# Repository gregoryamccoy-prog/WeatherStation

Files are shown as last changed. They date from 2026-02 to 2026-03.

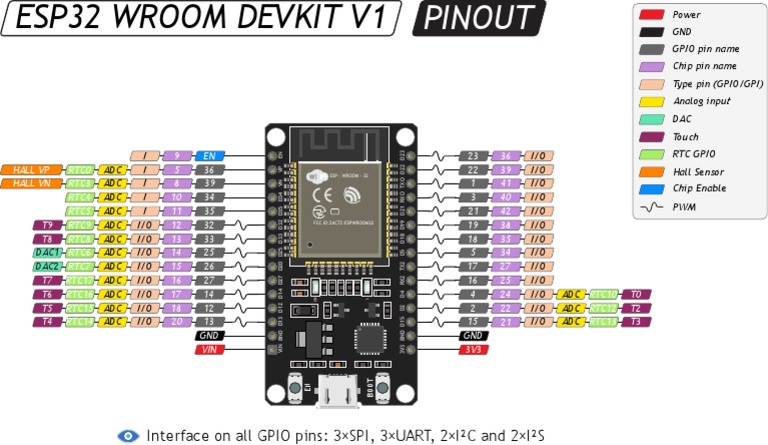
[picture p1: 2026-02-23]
zho_Esp32-Wroom-32-Arduino-Pinout.jpg

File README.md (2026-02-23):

# ESP32 Weather Station

A low-power indoor/outdoor weather station built on the ESP32 WROOM. It reads indoor conditions from a DHT11 sensor, fetches outdoor weather and a 3-day forecast from the [Open-Meteo](https://open-meteo.com/) API (no API key required), and renders the full layout onto a Waveshare 4.2" e-paper display. The device wakes every 10 minutes, completes its update cycle in under 15 seconds, then returns to deep sleep.

---

## Table of Contents

1. [Hardware Bill of Materials](#hardware-bill-of-materials)
2. [Wiring Diagram](#wiring-diagram)
3. [Pin Reference](#pin-reference)
4. [Software Setup](#software-setup)
5. [Configuration](#configuration)
6. [Build & Flash](#build--flash)
7. [Operation](#operation)
8. [Display Layout](#display-layout)
9. [Project Structure](#project-structure)
10. [Performance Targets](#performance-targets)
11. [Troubleshooting](#troubleshooting)

---

## Hardware Bill of Materials

| # | Component | Notes |
|---|---|---|
| 1 | **ESP32 WROOM Dev Module** | Any standard 38-pin board |
| 2 | **Waveshare 4.2" e-Paper Display** | Rev 2.1, GDEW042T2, 400 × 300 px B/W |
| 3 | **DHT11 Temperature & Humidity Sensor** | 3-pin breakout or 4-pin module with pull-up |
| 4 | **10 kΩ resistor** | Pull-up on DHT11 DATA line (omit if using breakout with built-in resistor) |
| 5 | **Breadboard / PCB + jumper wires** | — |
| 6 | **5 V USB power supply** | Powers the ESP32 via its onboard regulator |

---

## Wiring Diagram

```
                        ┌──────────────────────────────────────────┐
                        │           ESP32 Dev Module               │
                        │                                          │
          ┌─── 3.3V ────┤ 3V3                               GPIO23 ├──── MOSI ────┐
          │  ┌── GND ───┤ GND                               GPIO18 ├──── SCK  ────┤
          │  │          │                                   GPIO 5 ├──── CS   ────┤
          │  │          │                                   GPIO16 ├──── DC   ────┤  Waveshare
          │  │          │                                   GPIO17 ├──── RST  ────┤  4.2" e-Paper
          │  │          │                                   GPIO25 ├──── BUSY ────┘  (SPI)
          │  │          │                                          │
          │  │          │                                   GPIO26 ├──── DATA ────┐
          │  │          │                                          │              │  DHT11
          └──┼──────────┤ 3V3  ◄────────────────────────── VCC   │◄─────────────┤
             └──────────┤ GND  ◄────────────────────────── GND   │              │
                        └──────────────────────────────────────────┘             │
                                                                    10kΩ to 3.3V ┘
                                                                    (pull-up, if needed)
```

### Schematic (Mermaid)

```mermaid
graph TD
    subgraph ESP32["ESP32 WROOM Dev Module"]
        P23["GPIO 23 — MOSI"]
        P18["GPIO 18 — SCK"]
        P5["GPIO 5  — CS"]
        P16["GPIO 16 — DC"]
        P17["GPIO 17 — RST"]
        P25["GPIO 25 — BUSY"]
        P26["GPIO 26 — DHT DATA"]
        V33["3.3 V"]
        GND["GND"]
    end

    subgraph EPD["Waveshare 4.2&quot; e-Paper (SPI)"]
        E_DIN["DIN (MOSI)"]
        E_CLK["CLK (SCK)"]
        E_CS["CS"]
        E_DC["DC"]
        E_RST["RST"]
        E_BUSY["BUSY"]
        E_VCC["VCC"]
        E_GND["GND"]
    end

    subgraph DHT["DHT11 Sensor"]
        D_DATA["DATA"]
        D_VCC["VCC"]
        D_GND["GND"]
    end

    P23  --> E_DIN
    P18  --> E_CLK
    P5   --> E_CS
    P16  --> E_DC
    P17  --> E_RST
    E_BUSY --> P25
    V33  --> E_VCC
    GND  --> E_GND

    P26  --> D_DATA
    V33  --> D_VCC
    GND  --> D_GND
```

---

## Pin Reference

### e-Paper Display — SPI

| Display Pin | ESP32 GPIO | Notes |
|---|---|---|
| DIN (MOSI)  | **23** | SPI data |
| CLK (SCK) | **18** | SPI clock |
| CS | **5** | Chip select (active LOW) |
| DC | **16** | Data / Command select |
| RST | **17** | Hardware reset (active LOW) |
| BUSY | **25** | High while display is refreshing |
| VCC | 3.3 V | — |
| GND | GND | — |

### DHT11 Sensor

| Sensor Pin | ESP32 GPIO | Notes |
|---|---|---|
| DATA | **26** | Add 10 kΩ pull-up to 3.3 V if using bare IC |
| VCC | 3.3 V | — |
| GND | GND | — |

> **Note:** All signal lines run at 3.3 V logic. The ESP32's onboard 3.3 V LDO supplies both peripherals; total current draw at peak (Wi-Fi TX + SPI) stays well within its 600 mA rating.

---

## Software Setup

### Prerequisites

- [PlatformIO](https://platformio.org/) (VS Code extension or CLI)
- USB driver for your ESP32 board (CP210x or CH340, depending on board variant)

### Library Dependencies

Managed automatically by PlatformIO via `platformio.ini`:

| Library | Version | Purpose |
|---|---|---|
| `zinggjm/GxEPD2` | ^1.6.0 | e-Paper driver (GxEPD2_420 / GDEW042T2) |
| `bblanchon/ArduinoJson` | ^7.0.0 | JSON parsing (v7 `JsonDocument`) |
| `adafruit/DHT sensor library` | ^1.4.6 | DHT11 driver |
| `adafruit/Adafruit Unified Sensor` | ^1.1.14 | Sensor abstraction |
| `HTTPClient` | (bundled) | HTTP requests |
| `WiFiClientSecure` | (bundled) | HTTPS (TLS with `setInsecure()`) |
| `Preferences` | (bundled) | NVS storage |

---

## Configuration

### Wi-Fi Credentials — `secrets.h`

Create `secrets.h` in the **project root** (it is excluded from version control via `.gitignore`):

```cpp
// secrets.h
#pragma once

#define WIFI_SSID     "your-network-name"
#define WIFI_PASSWORD "your-network-password"
```

### Location & Time Zone — `src/config.h`

Edit these constants if you are not in Crestwood, KY:

```cpp
static constexpr double LOCATION_LAT  =  38.3242;
static constexpr double LOCATION_LON  = -85.4725;
static constexpr char   LOCATION_TZ[] = "America/New_York";
static constexpr char   LOCATION_NAME[] = "Crestwood, KY";

static constexpr long GMT_OFFSET_SEC  = -18000;   // UTC-5 (EST)
static constexpr int  DAYLIGHT_OFFSET = 3600;      // +1 h during EDT
```

> **Remember** to also update the latitude/longitude in `OPENMETEO_URL` inside `config.h` to match.

### Sleep Interval — `src/config.h`

```cpp
static constexpr uint64_t SLEEP_DURATION_US = 10ULL * 60ULL * 1000000ULL;  // 10 minutes
```

---

## Build & Flash

```bash
# Build only
pio run

# Build and upload
pio run --target upload

# Monitor serial output
pio device monitor --baud 115200
```

Or use the **PlatformIO: Build / Upload** buttons in VS Code.

> **Stack size:** The Arduino loop task stack is set to **16 KB** (`-DARDUINO_LOOP_STACK_SIZE=16384` in `platformio.ini`) to accommodate GxEPD2 page-buffered rendering alongside the `WeatherSnapshot` struct and font rendering.

---

## Operation

### Wake Sequence (every 10 minutes)

```
Power-on / RTC wakeup
        │
        ▼
  Init e-paper hardware (before Wi-Fi to avoid heap fragmentation)
        │
        ▼
  Connect Wi-Fi  ──(fail)──► render cached data → deep sleep
        │
        ▼
  NTP sync (once per calendar day)
        │
        ▼
  Read DHT11 (up to 3 retries, 2 s apart)
        │
        ▼
  HTTPS GET Open-Meteo API → getString() → deserializeJson()
        │
        ▼
  Write NVS trend record (once per calendar day, if sensor + API both OK)
        │
        ▼
  Render framebuffer → full e-paper refresh
        │
        ▼
  Deep sleep 10 min
```

### Offline Behaviour

If the Wi-Fi connection or API call fails, the device will:
- Display the last successfully fetched weather data (cached in RTC memory)
- Show "! Offline – cached data" warning and "Offline" in the top bar
- Still display live indoor sensor readings
- Continue the normal sleep / wake cycle

### RTC-Retained State

Across deep-sleep cycles, the following are preserved in RTC memory:
- Last successful `CurrentConditions` and `ForecastDay[3]`
- Timestamp of last successful API call
- Day-of-year of last NTP sync and last NVS trend write
- Wake counter

### NVS Trend Storage

Up to **365 daily records** are stored in NVS flash using a circular buffer. Each record (18 bytes) contains:
- Day index (days since epoch)
- Indoor temperature & humidity
- Outdoor temperature
- Barometric pressure

The **30 most recent** records are rendered as a dual-line trend graph at the bottom of the display (indoor = solid, outdoor = dotted).

---

## Display Layout

The display is a 400 × 300 px monochrome e-paper panel rendered with GxEPD2 page-buffered drawing and Adafruit GFX (FreeSans) fonts.

```
┌────────────────────────────────────────────────────────────────┐  y=0
│  22:05       Sun Feb 22                            Online     │  Top bar (22 px)
├──────────┬──────────────────────────┬─────────────────────────┤  y=22
│ INDOOR   │                          │  WIND                   │
│ 22.5°C   │      -4.7°              │  22 km/h                │
│ 32% RH   │   Partly Cloudy         │─────────────────────────│  Main panels
│──────────│      ⛅ (48×48 icon)     │  PRESSURE               │  (133 px)
│          │                          │  1018 hPa               │
│          │                          │─────────────────────────│
│          │                          │  HUMIDITY               │
│          │                          │  74%                    │
├──────────┴──────────────────────────┴─────────────────────────┤  y=155
│    TODAY         TMRW          +2 DAY                         │
│  4 / -1°C     6 / 0°C        8 / 2°C                         │  Forecast (62 px)
│  Rain 20%     Rain 60%       Rain 10%                         │
├───────────────────────────────────────────────────────────────┤  y=217
│  Rise 07:12     Set 17:48     Wax Cresc                       │  Astronomy (20 px)
├───────────────────────────────────────────────────────────────┤  y=237
│  30d  IN ───  OUT · · ·   (auto-scaled line graph)            │  Trend graph (63 px)
└───────────────────────────────────────────────────────────────┘  y=300
```

**Panel widths:** Left 100 px · Centre 200 px · Right 100 px

### Fonts

| Zone | Font | Size |
|---|---|---|
| Top bar | FreeSansBold | 9 pt |
| Indoor label | FreeSans | 9 pt |
| Indoor temp | FreeSansBold | 12 pt |
| Outdoor temp | FreeSansBold | 18 pt |
| Weather desc | FreeSans | 9 pt |
| Right panel labels | FreeSans | 9 pt |
| Right panel values | FreeSansBold | 9 pt |
| Forecast day labels | FreeSansBold | 9 pt |
| Forecast data | FreeSans | 9 pt |
| Astronomy bar | FreeSans | 9 pt |
| Trend graph label | Built-in 6×8 | 1× |

### Weather Icons

48 × 48 px icons drawn with Adafruit GFX primitives (circles, lines, rectangles) — no bitmaps. Mapped from WMO weather codes:

| WMO Code | Icon | Description |
|---|---|---|
| 0 | Sun | Clear sky |
| 1–3 | Sun + cloud | Partly cloudy |
| 45–48 | Dashed lines | Fog |
| 51–67 | Cloud + drops | Rain |
| 71–77 | Cloud + flakes | Snow |
| 80–82 | Outline cloud + drops | Showers |
| 95–99 | Cloud + bolt | Thunderstorm |
| Other | Circle + ? | Unknown |

### Moon Phase

Calculated locally from a synodic-period algorithm (reference new moon: 2000-01-06 18:14 UTC). Labels: New, Wax Cresc, 1stQtr, Wax Gibb, Full, Wan Gibb, LastQtr, Wan Cresc.

---

## Project Structure

```
WeatherStation/
├── platformio.ini              # Build config, libs, stack size (16 KB)
├── secrets.h                   # Wi-Fi credentials (git-ignored)
├── README.md                   # This file
├── ESP32 Weather Station – Product Requirements.md
└── src/
    ├── main.cpp                # Wake/sleep orchestration, RTC-retained state
    ├── config.h                # Pins, API URL, layout geometry, NVS keys
    ├── data_model.h            # Shared structs (CurrentConditions, ForecastDay,
    │                           #   DailyTrend, SensorReading, WeatherSnapshot)
    ├── wifi_manager/           # Wi-Fi connect/disconnect with configurable timeout
    │   ├── wifi_manager.h
    │   └── wifi_manager.cpp
    ├── ntp_service/            # SNTP sync (once per calendar day via RTC check)
    │   ├── ntp_service.h
    │   └── ntp_service.cpp
    ├── openmeteo_client/       # HTTPS GET → getString() → ArduinoJson v7 parsing
    │   ├── openmeteo_client.h  #   Moon phase calculated locally (not from API)
    │   └── openmeteo_client.cpp
    ├── sensor_service/         # DHT11 read with retry logic (up to 3 attempts)
    │   ├── sensor_service.h
    │   └── sensor_service.cpp
    ├── trend_storage/          # NVS circular buffer (365 records, daily writes)
    │   ├── trend_storage.h
    │   └── trend_storage.cpp
    ├── display_renderer/       # GxEPD2 page-buffered layout, GFX fonts & icons
    │   ├── display_renderer.h
    │   ├── display_renderer.cpp
    │   └── icon_renderer.h     # 48×48 vector icons drawn via GFX primitives
    └── power_manager/          # Deep sleep entry
        ├── power_manager.h
        └── power_manager.cpp
```

---

## Performance Targets

| Metric | Target |
|---|---|
| Wi-Fi connect | < 4 s |
| API call + parse | < 3 s |
| Render + refresh | < 4 s |
| **Total active time** | **≤ 15 s** |
| Sleep current | ~10 µA (ESP32 deep sleep) |
| Wake interval | 10 minutes |
| RAM usage | ~19% (62 KB / 328 KB) |
| Flash usage | ~49% (953 KB / 1966 KB) |

---

## Weather API

**Provider:** [Open-Meteo](https://open-meteo.com/) — no API key required.

**Endpoint (configured in `src/config.h`):**
```
https://api.open-meteo.com/v1/forecast
  ?latitude=38.3242&longitude=-85.4725
  &current=temperature_2m,relative_humidity_2m,pressure_msl,wind_speed_10m,weather_code
  &daily=weather_code,temperature_2m_max,temperature_2m_min,
         precipitation_probability_max,sunrise,sunset
  &timezone=auto
  &forecast_days=3
```

A single HTTPS request returns current conditions and a 3-day forecast (~3 KB payload), minimising Wi-Fi on-time per cycle. Moon phase is computed locally rather than requested from the API.

---

## Troubleshooting

| Symptom | Cause | Fix |
|---|---|-----|
| `JSON parse error: InvalidInput` | Chunked transfer encoding on HTTPS stream | Fixed: uses `getString()` instead of stream parsing |
| `stack overflow in task loopTask` | Default 8 KB stack too small for GxEPD2 + fonts | Fixed: stack set to 16 KB in `platformio.ini` |
| Display renders upside-down | Wrong `setRotation()` value | Set `display.setRotation(0)` for connector-at-top mounting |
| Text overlapping / 2× scale | Icon renderer leaking `setTextSize(2)` | Fixed: `drawUnknown()` now resets to `setTextSize(1)` |
| DHT reads `NaN` | Sensor needs 2 s warm-up after power-on | Built-in: 2 s delay on first read, 3 retries |
| Wi-Fi fails | Weak signal or wrong credentials | Check `secrets.h`; timeout is 20 s (configurable) |

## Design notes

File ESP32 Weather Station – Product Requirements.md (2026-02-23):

# ESP32 Weather Station – Product Requirements Document (PRD)

## 1. Product Overview

### 1.1 Objective

Design a low-power ESP32-based indoor/outdoor weather station that:

- Measures indoor temperature and humidity using a DHT11 sensor
- Retrieves outdoor weather and a 3-day forecast from the Open-Meteo API (no API key)
- Displays sunrise, sunset, and lunar phase
- Stores long-term trend data in NVS flash (365 days)
- Operates on a 10-minute deep-sleep cycle
- Renders all data onto a Waveshare 4.2" 400 × 300 e-paper display

### 1.2 Hardware

| Component | Detail |
|---|---|
| MCU | ESP32 WROOM (esp32dev) |
| Display | Waveshare 4.2" 400 × 300 B/W e-paper, Rev 2.1 (GDEW042T2) |
| Sensor | DHT11 (temperature + humidity) |
| Build platform | PlatformIO, Arduino framework |

### 1.3 Location

Crestwood, Kentucky (38.3242, -85.4725). Timezone: America/New_York. Units: Metric.

---

## 2. Weather Data Provider

### 2.1 Selected Service: Open-Meteo

- **No API key required** — eliminates TLS token exchange overhead and rate-limit concerns for a single device.
- Base URL: `https://api.open-meteo.com/v1/forecast`

### 2.2 API Request

```
https://api.open-meteo.com/v1/forecast
  ?latitude=38.3242&longitude=-85.4725
  &current=temperature_2m,relative_humidity_2m,pressure_msl,wind_speed_10m,weather_code
  &daily=weather_code,temperature_2m_max,temperature_2m_min,
         precipitation_probability_max,sunrise,sunset
  &timezone=auto
  &forecast_days=3
```

A single HTTPS request returns:
- Current conditions (temperature, humidity, pressure, wind, WMO weather code)
- 3-day daily forecast (min/max temp, rain probability, sunrise, sunset)

**Moon phase** is not requested from the API; it is calculated locally using a synodic-period algorithm.

### 2.3 Response Handling

- HTTPS via `WiFiClientSecure` with `setInsecure()` (no CA bundle on device).
- Full response body read via `http.getString()` to correctly handle chunked transfer encoding.
- Parsed with ArduinoJson v7 (`JsonDocument`, heap-allocated, ~3–5 KB payload).

---

## 3. Weather Code → Icon Mapping

Open-Meteo uses WMO numeric `weather_code` values. The firmware maps these to vector icons drawn with Adafruit GFX primitives (48 × 48 px, no bitmaps):

| WMO Code | Icon | Description |
|---|---|---|
| 0 | Sun | Clear sky |
| 1–3 | Sun + cloud | Partly cloudy |
| 45–48 | Dashed lines | Fog |
| 51–67 | Cloud + drops | Rain |
| 71–77 | Cloud + flakes | Snow |
| 80–82 | Outline cloud + drops | Showers |
| 95–99 | Cloud + bolt | Thunderstorm |
| Other | Circle + ? | Unknown |

---

## 4. Data Model

### 4.1 Current Conditions

```cpp
struct CurrentConditions {
    float   outdoorTemp;     // °C
    float   pressure;        // hPa
    float   windSpeed;       // km/h
    int     humidity;        // %
    uint8_t weatherCode;     // WMO code
    bool    valid;
};
```

### 4.2 Forecast

```cpp
struct ForecastDay {
    float   minTemp;         // °C
    float   maxTemp;         // °C
    int     rainChance;      // %
    uint8_t weatherCode;
    char    sunrise[6];      // "HH:MM\0"
    char    sunset[6];
    char    moonPhase[16];   // e.g. "Wax Cresc"
    bool    valid;
};
```

### 4.3 Trend Record (NVS)

```cpp
struct DailyTrend {
    uint16_t dayIndex;       // days since epoch
    float    indoorTemp;
    float    indoorHumidity;
    float    outdoorTemp;
    float    pressure;
};
```

- Retention: 365 records in a circular NVS buffer
- Written once per calendar day (only when both sensor and API data are valid)

### 4.4 Indoor Sensor Reading

```cpp
struct SensorReading {
    float temperature;    // °C
    float humidity;       // %
    bool  valid;
};
```

### 4.5 Aggregate Snapshot

```cpp
struct WeatherSnapshot {
    CurrentConditions current;
    ForecastDay       forecast[3];
    SensorReading     indoor;
    DailyTrend        graph[30];   // last ≤30 records for trend graph
    uint8_t           graphCount;
    bool              apiOk;
    time_t            lastUpdate;
};
```

---

## 5. Power and Runtime Model

- **Wake interval:** 10 minutes (configurable via `SLEEP_DURATION_US`)
- **Sleep current:** ~10 µA (ESP32 deep sleep)
- **Target active time:** ≤ 15 seconds

### Active Sequence

1. Init e-paper hardware (before Wi-Fi to avoid heap fragmentation)
2. Connect Wi-Fi (20 s timeout)
3. NTP sync (once per calendar day, tracked via RTC-retained day-of-year)
4. Read DHT11 (up to 3 retries, 2 s between attempts)
5. HTTPS GET Open-Meteo API → `getString()` → `deserializeJson()`
6. Write NVS trend record (once per calendar day)
7. Render framebuffer → full e-paper refresh
8. Deep sleep

### RTC-Retained State

Preserved across deep-sleep cycles:
- Last successful `CurrentConditions` and `ForecastDay[3]`
- Timestamp of last API success
- Day-of-year of last NTP sync and NVS write
- Wake counter

---

## 6. Display Layout

**Resolution:** 400 × 300 px, 1-bit monochrome  
**Driver:** GxEPD2_BW with GxEPD2_420 (page-buffered rendering)  
**Rotation:** 0° (connector at top)

### Layout Zones

| Zone | Y start | Height | Content |
|---|---|---|---|
| Top bar | 0 | 22 px | Time (left), date (centre), Online/Offline (right) |
| Main panels | 22 | 133 px | Left (100 px): indoor. Centre (200 px): outdoor temp + icon. Right (100 px): wind, pressure, humidity |
| Forecast row | 155 | 62 px | 3 columns (133 px each): TODAY, TMRW, +2 DAY with max/min and rain % |
| Astronomy bar | 217 | 20 px | Sunrise, sunset, moon phase label |
| Trend graph | 237 | 63 px | 30-day indoor (solid) + outdoor (dotted) line graph, auto-scaled |

### Fonts

- **FreeSansBold 18pt:** Outdoor temperature (centre panel)
- **FreeSansBold 12pt:** Indoor temperature
- **FreeSansBold 9pt:** Top bar, forecast day labels, panel values
- **FreeSans 9pt:** Labels, descriptions, forecast data, astronomy bar
- **Built-in 6×8:** Trend graph legend

### Moon Phase

Computed locally via synodic-period algorithm (reference new moon: 2000-01-06 18:14 UTC, period: 29.53059 days). Labels: New, Wax Cresc, 1stQtr, Wax Gibb, Full, Wan Gibb, LastQtr, Wan Cresc.

---

## 7. Memory Budget

### 7.1 JSON Document

- Open-Meteo payload (filtered fields): ~3–5 KB
- ArduinoJson v7 `JsonDocument` (heap-allocated, auto-sized)

### 7.2 Framebuffer

- 400 × 300 monochrome: ~15 KB
- GxEPD2 uses page-buffered rendering (not full framebuffer)

### 7.3 Stack

- Arduino loop task stack: **16 KB** (`-DARDUINO_LOOP_STACK_SIZE=16384`)
- Required by GxEPD2 page-write + Adafruit GFX font rendering + `WeatherSnapshot` on stack

### 7.4 Overall

- RAM usage: ~19% (62 KB / 328 KB)
- Flash usage: ~49% (953 KB / 1966 KB)

---

## 8. Flash Storage Strategy

- **Daily write only** — one NVS record per calendar day
- NVS circular buffer: 365 records × 18 bytes ≈ 6.4 KB
- Partition scheme: `min_spiffs.csv` (maximises NVS headroom)
- Flash lifetime: multi-decade at one write/day

---

## 9. Connectivity Behaviour

If API call or Wi-Fi fails:
- Use cached weather data from RTC memory
- Show "! Offline – cached data" overlay + "Offline" in top bar
- Still display live indoor sensor readings
- Continue normal sleep cycle

---

## 10. Firmware Modules

| Module | Directory | Responsibility |
|---|---|---|
| `wifi_manager` | `src/wifi_manager/` | Connect/disconnect with configurable timeout |
| `ntp_service` | `src/ntp_service/` | SNTP sync, once per calendar day |
| `openmeteo_client` | `src/openmeteo_client/` | HTTPS fetch, JSON parse, moon phase calc |
| `sensor_service` | `src/sensor_service/` | DHT11 read with 3-retry logic |
| `trend_storage` | `src/trend_storage/` | NVS circular buffer (365 records) |
| `display_renderer` | `src/display_renderer/` | GxEPD2 layout, fonts, vector icons |
| `power_manager` | `src/power_manager/` | Deep sleep entry |

---

## 11. Performance Targets

| Metric | Target |
|---|---|
| Wi-Fi connect | < 4 s |
| API call + parse | < 3 s |
| Render + refresh | < 4 s |
| **Total active time** | **≤ 15 s** |
| Sleep current | ~10 µA |
| Wake interval | 10 min |

---

## 12. Build Environment

- **PlatformIO** with Arduino framework
- Board: `esp32dev`
- Partition: `min_spiffs.csv`
- Stack: 16 KB loop task
- Libraries: GxEPD2 ^1.6.0, ArduinoJson ^7.0.0, DHT sensor library ^1.4.6, Adafruit Unified Sensor ^1.1.14

---

## 13. Acceptance Criteria

The system shall:

1. Operate with no API key (Open-Meteo)
2. Wake every 10 minutes from deep sleep
3. Display indoor temperature and humidity from DHT11
4. Display outdoor conditions (temp, wind, pressure, humidity, weather icon)
5. Display 3-day forecast (min/max, rain probability)
6. Display sunrise, sunset, and computed moon phase
7. Maintain 365-day trend history in NVS
8. Render 30-day dual-line trend graph (indoor + outdoor)
9. Enter deep sleep automatically after each refresh
10. Recover gracefully from Wi-Fi and API failures using cached data
11. Complete full wake cycle in ≤ 15 seconds
12. Fit within ESP32 RAM (~19%) and flash (~49%) budgets

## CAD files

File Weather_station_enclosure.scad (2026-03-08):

$fn = 96;

// Debug switches
SHOW_2D_ONLY  = true;   // set false once you see silhouette
SHOW_OUTER_3D = false;  // set true to see an extruded slab

tilt_deg   = 10;
fillet_r   = 30;

base_depth = 95;
base_h     = 26;

blade_h    = 135;
blade_back = 10;

module outer_2d() {
  hull() {
    // Base rectangle (electronics volume)
    square([base_depth, base_h], center=false);

    // Blade rectangle (screen “sheet”), tilted
    translate([base_depth - blade_back - 2, base_h])
      rotate(-tilt_deg)
        square([blade_back, blade_h], center=false);

    // Circle to encourage a smooth bend
    translate([base_depth - fillet_r - 6, base_h - fillet_r])
      circle(r=fillet_r);
  }
}

if (SHOW_2D_ONLY) {
  outer_2d();
} else if (SHOW_OUTER_3D) {
  linear_extrude(height=20) outer_2d();
}

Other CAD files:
Enclosure.FCStd

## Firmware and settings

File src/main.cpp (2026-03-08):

// main.cpp — Wake / sleep orchestration for ESP32 Weather Station
//
// Wake sequence:
//   Power on → WiFi → NTP (once/day) → DHT11 → Open-Meteo API →
//   Parse → Render → EPD refresh → Deep sleep 10 min

#include <Arduino.h>
#include <time.h>

#include "config.h"
#include "data_model.h"
#include "secrets.h"

#include "wifi_manager/wifi_manager.h"
#include "ntp_service/ntp_service.h"
#include "openmeteo_client/openmeteo_client.h"
#include "sensor_service/sensor_service.h"
#include "display_renderer/display_renderer.h"
#include "power_manager/power_manager.h"

// ---------------------------------------------------------------------------
// RTC-retained state (survives deep sleep)
// ---------------------------------------------------------------------------
RTC_DATA_ATTR static bool            rtc_initialized         = false;
RTC_DATA_ATTR static CurrentConditions rtc_lastCurrent       = {};
RTC_DATA_ATTR static ForecastDay     rtc_lastForecast[3]     = {};
RTC_DATA_ATTR static time_t          rtc_lastApiSuccess      = 0;
RTC_DATA_ATTR static int             rtc_lastNtpDay          = -1;    // day-of-year of last NTP sync
RTC_DATA_ATTR static uint32_t        rtc_wakeCount           = 0;

// ---------------------------------------------------------------------------
// Helpers
// ---------------------------------------------------------------------------
static int dayOfYear(const struct tm* t) {
    return t->tm_yday;
}

// ---------------------------------------------------------------------------
// setup() — runs once per wake from deep sleep
// ---------------------------------------------------------------------------
void setup() {
    Serial.begin(115200);
    delay(200);   // allow USB-serial bridge to enumerate before first print
    Serial.printf("\n[main] Wake #%u\n", rtc_wakeCount++);

    // -----------------------------------------------------------------------
    // 0. Initialise display hardware FIRST — grabs GxEPD2 heap/DMA allocations
    //    before WiFi stack fragments the heap.
    // -----------------------------------------------------------------------
    DisplayRenderer::init();

    // -----------------------------------------------------------------------
    // 1. Connect to Wi-Fi
    // -----------------------------------------------------------------------
    bool wifiOk = WifiManager::connect(WIFI_SSID, WIFI_PASSWORD, WIFI_CONNECT_TIMEOUT);
    if (!wifiOk) {
        Serial.println("[main] Wi-Fi failed – rendering cached data");
        // Still render whatever is cached so the display doesn't go blank
        WeatherSnapshot snap = {};
        snap.apiOk           = false;
        snap.indoor          = SensorService::read();
        snap.current         = rtc_lastCurrent;
        snap.lastUpdate      = rtc_lastApiSuccess;
        for (int i = 0; i < 3; i++) snap.forecast[i] = rtc_lastForecast[i];
        DisplayRenderer::render(snap);
        PowerManager::deepSleep(SLEEP_DURATION_US);
        return;
    }

    // -----------------------------------------------------------------------
    // 2. NTP sync (once per calendar day)
    // -----------------------------------------------------------------------
    struct tm timeinfo = {};
    bool timeValid     = NtpService::getTime(timeinfo);

    if (!timeValid || dayOfYear(&timeinfo) != rtc_lastNtpDay) {
        Serial.println("[main] Syncing NTP...");
        NtpService::sync();
        if (NtpService::getTime(timeinfo)) {
            rtc_lastNtpDay = dayOfYear(&timeinfo);
            Serial.printf("[main] NTP synced – day %d\n", rtc_lastNtpDay);
        }
    }

    // -----------------------------------------------------------------------
    // 3. Read DHT11
    // -----------------------------------------------------------------------
    SensorReading indoor = SensorService::read();
    Serial.printf("[main] Indoor %.1f°C  %.0f%%RH  valid=%d\n",
                  indoor.temperature, indoor.humidity, indoor.valid);

    // -----------------------------------------------------------------------
    // 4. Fetch Open-Meteo
    // -----------------------------------------------------------------------
    CurrentConditions current   = {};
    ForecastDay       forecast[3] = {};
    bool apiOk = OpenMeteoClient::fetch(current, forecast);

    if (apiOk) {
        rtc_lastCurrent   = current;
        for (int i = 0; i < 3; i++) rtc_lastForecast[i] = forecast[i];
        rtc_lastApiSuccess = time(nullptr);
        Serial.printf("[main] API OK – %.1f°C wmo=%d\n",
                      current.outdoorTemp, current.weatherCode);
    } else {
        Serial.println("[main] API failed – using cached outdoor data");
        current = rtc_lastCurrent;
        for (int i = 0; i < 3; i++) forecast[i] = rtc_lastForecast[i];
    }

    // -----------------------------------------------------------------------
    // 5. Disconnect Wi-Fi (saves ~70 mA during render)
    // -----------------------------------------------------------------------
    WifiManager::disconnect();

    // -----------------------------------------------------------------------
    // 6. Assemble snapshot and render
    // -----------------------------------------------------------------------
    WeatherSnapshot snap = {};
    snap.current     = current;
    snap.indoor      = indoor;
    snap.apiOk       = apiOk;
    snap.lastUpdate  = rtc_lastApiSuccess;
    for (int i = 0; i < 3; i++) snap.forecast[i] = forecast[i];

    DisplayRenderer::render(snap);

    // -----------------------------------------------------------------------
    // 7. Deep sleep
    // -----------------------------------------------------------------------
    Serial.printf("[main] Entering deep sleep for %llu s\n",
                  SLEEP_DURATION_US / 1000000ULL);
    PowerManager::deepSleep(SLEEP_DURATION_US);
}

// loop() is never reached — device wakes fresh each cycle via deep sleep reset
void loop() {}

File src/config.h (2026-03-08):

// config.h — Global pin assignments, API constants, and tuneable parameters
#pragma once

#include <cstdint>

// ---------------------------------------------------------------------------
// Hardware pins  (Waveshare ESP32 driver board defaults)
// ---------------------------------------------------------------------------
// E-paper SPI
static constexpr uint8_t PIN_EPD_MOSI  = 23;
static constexpr uint8_t PIN_EPD_SCK   = 18;
static constexpr uint8_t PIN_EPD_CS    = 5;
static constexpr uint8_t PIN_EPD_DC    = 16;
static constexpr uint8_t PIN_EPD_RST   = 17;
static constexpr uint8_t PIN_EPD_BUSY  = 25;

// DHT11 sensor
static constexpr uint8_t PIN_DHT       = 26;
static constexpr uint8_t DHT_TYPE      = 11;   // DHT11

// ---------------------------------------------------------------------------
// Location & units
// ---------------------------------------------------------------------------
static constexpr double LOCATION_LAT  =  38.3242;
static constexpr double LOCATION_LON  = -85.4725;
static constexpr char   LOCATION_TZ[] = "America/New_York";   // used in API request
static constexpr char   LOCATION_NAME[] = "Crestwood, KY";

// ---------------------------------------------------------------------------
// Open-Meteo REST endpoint  (no API key required)
// ---------------------------------------------------------------------------
static constexpr char OPENMETEO_HOST[] = "api.open-meteo.com";
static constexpr char OPENMETEO_URL[]  =
    "https://api.open-meteo.com/v1/forecast"
    "?latitude=38.3242&longitude=-85.4725"
    "&current=temperature_2m,relative_humidity_2m,pressure_msl,wind_speed_10m,weather_code"
    "&daily=weather_code,temperature_2m_max,temperature_2m_min"
    ",precipitation_probability_max,sunrise,sunset"
    "&timezone=auto"
    "&forecast_days=3";

// ---------------------------------------------------------------------------
// NTP
// ---------------------------------------------------------------------------
static constexpr char NTP_SERVER1[]    = "pool.ntp.org";
static constexpr char NTP_SERVER2[]    = "time.nist.gov";
static constexpr long GMT_OFFSET_SEC   = -18000;   // UTC-5 (EST); DST handled by TZ env
static constexpr int  DAYLIGHT_OFFSET  = 3600;     // +1 h during EDT

// ---------------------------------------------------------------------------
// Power management
// ---------------------------------------------------------------------------
static constexpr uint64_t SLEEP_DURATION_US = 10ULL * 60ULL * 1000000ULL;  // 10 minutes

// ---------------------------------------------------------------------------
// Display geometry (Waveshare 4.2" 400×300 Rev 2.1)
// ---------------------------------------------------------------------------
static constexpr uint16_t EPD_WIDTH  = 400;
static constexpr uint16_t EPD_HEIGHT = 300;

// Layout zones (x, y, w, h)
static constexpr uint16_t TOPBAR_H          = 24;
static constexpr uint16_t FORECAST_ROW_Y    = 200;
static constexpr uint16_t FORECAST_ROW_H    = 58;
static constexpr uint16_t MAIN_PANEL_H      = FORECAST_ROW_Y - TOPBAR_H;

// Left / centre / right panel widths
static constexpr uint16_t LEFT_PANEL_W      = 110;
static constexpr uint16_t RIGHT_PANEL_W     = 110;
static constexpr uint16_t CENTRE_PANEL_W    = EPD_WIDTH - LEFT_PANEL_W - RIGHT_PANEL_W;

// ---------------------------------------------------------------------------
// Application constants
// ---------------------------------------------------------------------------
static constexpr uint8_t  WIFI_CONNECT_TIMEOUT  = 20;    // seconds
static constexpr uint8_t  DHT_READ_RETRIES      = 3;
static constexpr uint16_t JSON_DOC_SIZE         = 8192;

// ---------------------------------------------------------------------------
// Icon dimensions
// ---------------------------------------------------------------------------
static constexpr uint8_t ICON_SIZE = 48;   // 48×48 px, 1-bit

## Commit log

2026-02-23 Initial commit: ESP32 e-paper weather station
    - 4.2" Waveshare e-paper (400x300) with GxEPD2
    - DHT11 indoor temperature/humidity sensor
    - Open-Meteo API for outdoor conditions & 3-day forecast
    - NTP time sync, astronomy bar (sunrise/sunset/moon phase)
    - 30-day trend graph stored in NVS
    - Deep sleep power management (10 min cycle)
2026-02-23 Update README and PRD to match actual implementation
    - Display layout: correct panel widths (100/200/100), zone heights,
    y-offsets, and font assignments to match display_renderer.cpp
    - API: document actual Open-Meteo URL (no moonrise/moonset params);
    moon phase is calculated locally via synodic algorithm
    - JSON parsing: document getString() approach (not stream parsing)
    - Stack: document 16 KB loop task stack (was 8 KB)
    - ArduinoJson: v7 JsonDocument (not v6 DynamicJsonDocument)
    - Data model: add SensorReading and WeatherSnapshot structs to PRD
    - Add Troubleshooting section covering resolved issues
    - Add RTC-retained state documentation
    - Remove stale weatherapi.com reference from PRD
    -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
2026-03-08 Replace trend graph with moon phase panel; fix WMO codes and moon calc
    - Remove TrendStorage module entirely (trend_storage.cpp/.h)
    - Add moonPhaseFraction field to ForecastDay
    - Fix moon phase reference timestamp (946937640 → 947182440)
    - Add drawMoonDisc() to icon_renderer.h (black disc, white illuminated region)
    - Replace drawTrendGraph() with drawMoonPanel() in display_renderer
    - Add OUTDOOR label to centre panel; fix WMO code 3 (Overcast) and 85-86 (Snow showers)
    - Add moon phase name to astronomy bar
    [Enclosure.FCStd, Weather_station_enclosure.scad]
